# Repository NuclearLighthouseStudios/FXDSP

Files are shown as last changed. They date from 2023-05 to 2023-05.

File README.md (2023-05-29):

# FXDSP — A WhateverDSP based guitar pedal

FXDSP is an easily programmable DSP platform in a familiar guitar pedal form factor:

FXDSP collage

It's based around an STM32F405 microcontroller and runs on the [WhateverDSP framework](https://github.com/NuclearLighthouseStudios/WhateverDSP),
offering low latency audio processing and fully class complicant USB audio and MIDI support.

FXDSP has interchangeable user interface PCBs so it can easily be tailored to the needs of each effect produced on the platform.

For more information about WhateverDSP, [please see the WhateverDSP repository](https://github.com/NuclearLighthouseStudios/WhateverDSP).

## Example code

Here is a full example showing a simple volume control that scales the audio level using a potentiometer:

```c
#include <libwdsp.h>

void wdsp_init(void)
{
	io_digital_out(BYPASS_L, true);
	io_digital_out(BYPASS_R, true);
}

void wdsp_process(float *in_buffer[BLOCK_SIZE], float *out_buffer[BLOCK_SIZE])
{
	float volume = io_analog_in(POT_1);

	for (int i = 0; i < BLOCK_SIZE; i++)
	{
		float l_sample = in_buffer[0][i];
		float r_sample = in_buffer[1][i];

		out_buffer[0][i] = l_sample * volume;
		out_buffer[1][i] = r_sample * volume;
	}
}

```

Check out the [examples repository](https://github.com/NuclearLighthouseStudios/WhateverDSP-Examples) for more,
or [come chat with us on Discord](https://github.com/NuclearLighthouseStudios/FXDSP#chat).

## Chat

[You can chat with us on Discord.](https://discord.gg/WDsFnartXb)

## License

FXDSP hardware is licensed under CC-BY-NC-SA.

The WhateverDSP library is licensed under GNU Lesser General Public License.

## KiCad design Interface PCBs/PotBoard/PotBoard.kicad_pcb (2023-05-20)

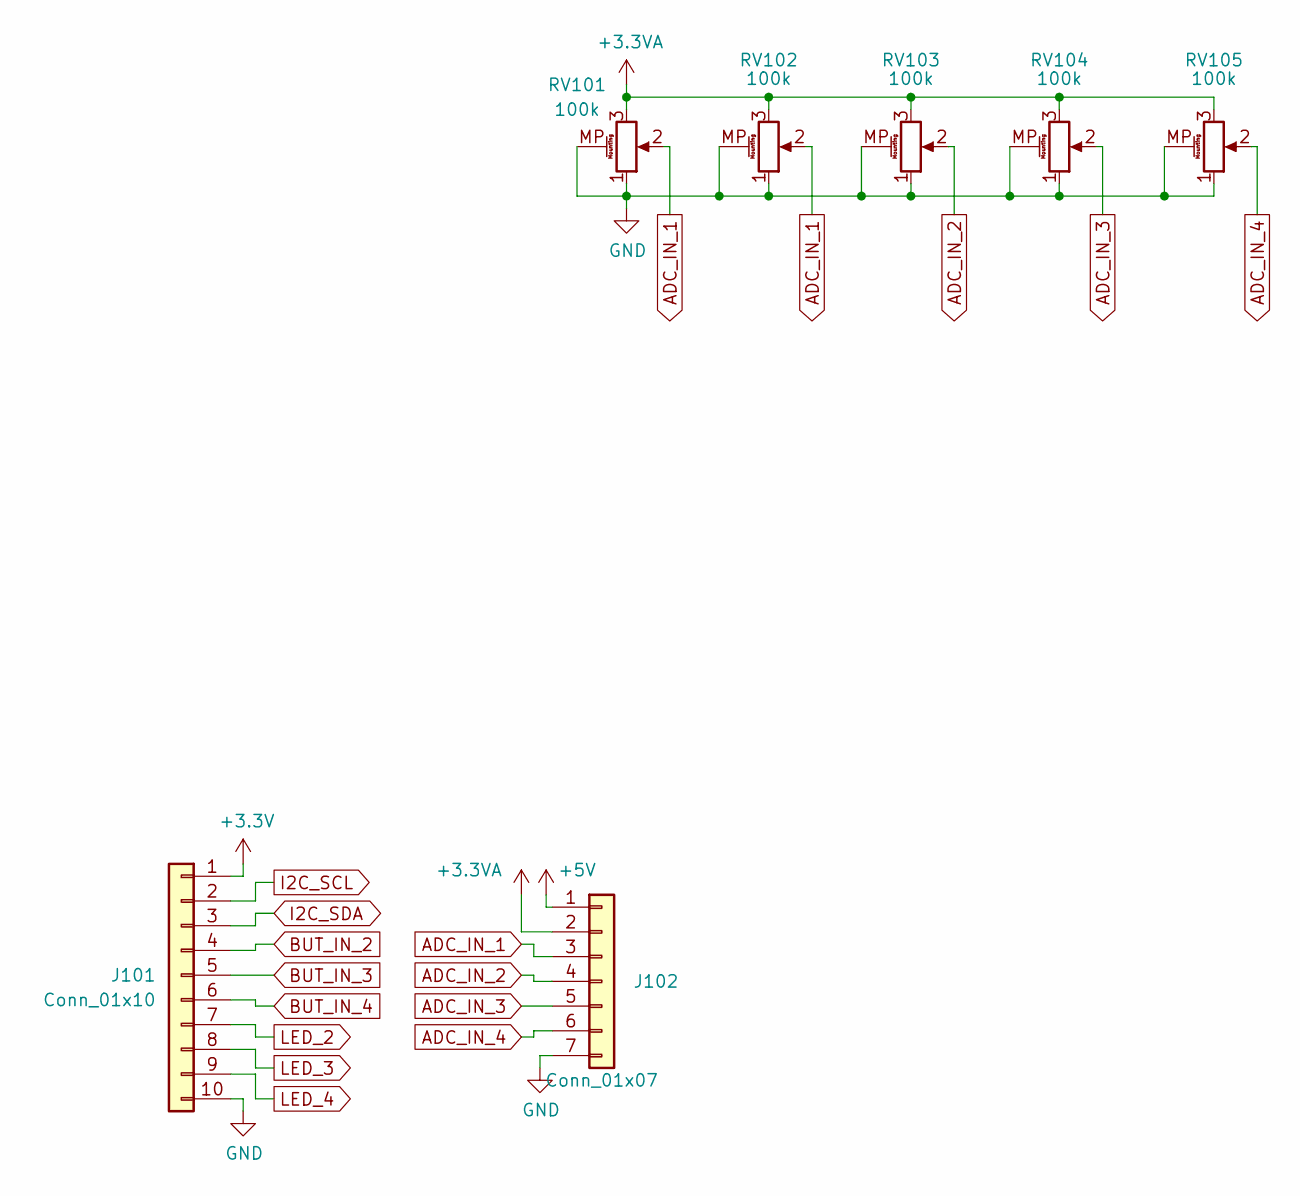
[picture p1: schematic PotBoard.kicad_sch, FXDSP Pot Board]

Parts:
J101: Conn_01x10; PinHeader_1x10_P2.54mm_Vertical
J102: Conn_01x07; PinHeader_1x07_P2.54mm_Vertical
RV101, RV102, RV103, RV104, RV105: 100k; Potentiometer_Alps_RK09K_Single_Vertical

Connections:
+3.3V: J101.1
+3.3VA: J102.2, RV101.3, RV102.3, RV103.3, RV104.3, RV105.3
+5V: J102.1
ADC_IN_1: J102.3, RV101.2, RV102.2
ADC_IN_2: J102.4, RV103.2
ADC_IN_3: J102.5, RV104.2
ADC_IN_4: J102.6, RV105.2
BUT_IN_2: J101.4
BUT_IN_3: J101.5
BUT_IN_4: J101.6
GND: J101.10, J102.7, RV101.1, RV101.MP (MountPin), RV102.1, RV102.MP (MountPin), RV103.1, RV103.MP (MountPin), RV104.1, RV104.MP (MountPin), RV105.1, RV105.MP (MountPin)
I2C_SCL: J101.2
I2C_SDA: J101.3
LED_2: J101.7
LED_3: J101.8
LED_4: J101.9

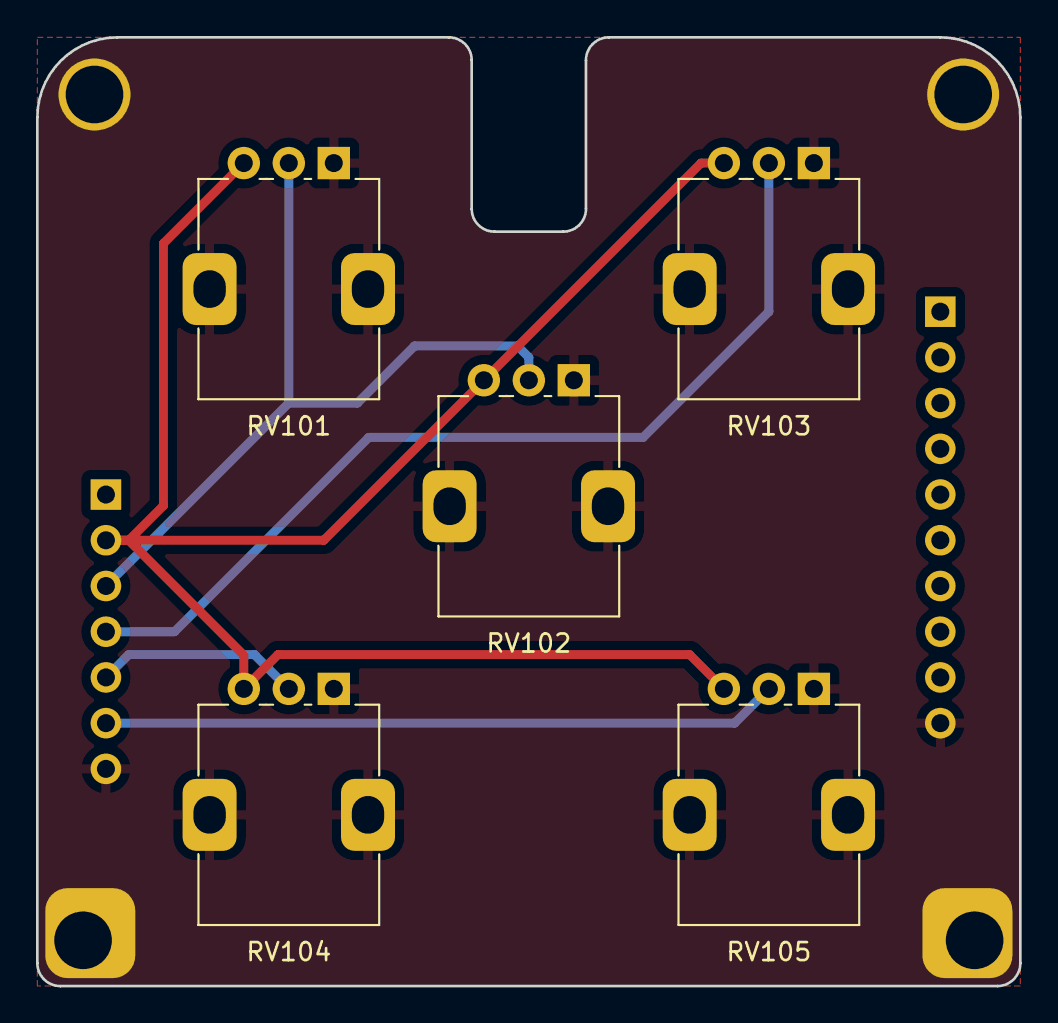
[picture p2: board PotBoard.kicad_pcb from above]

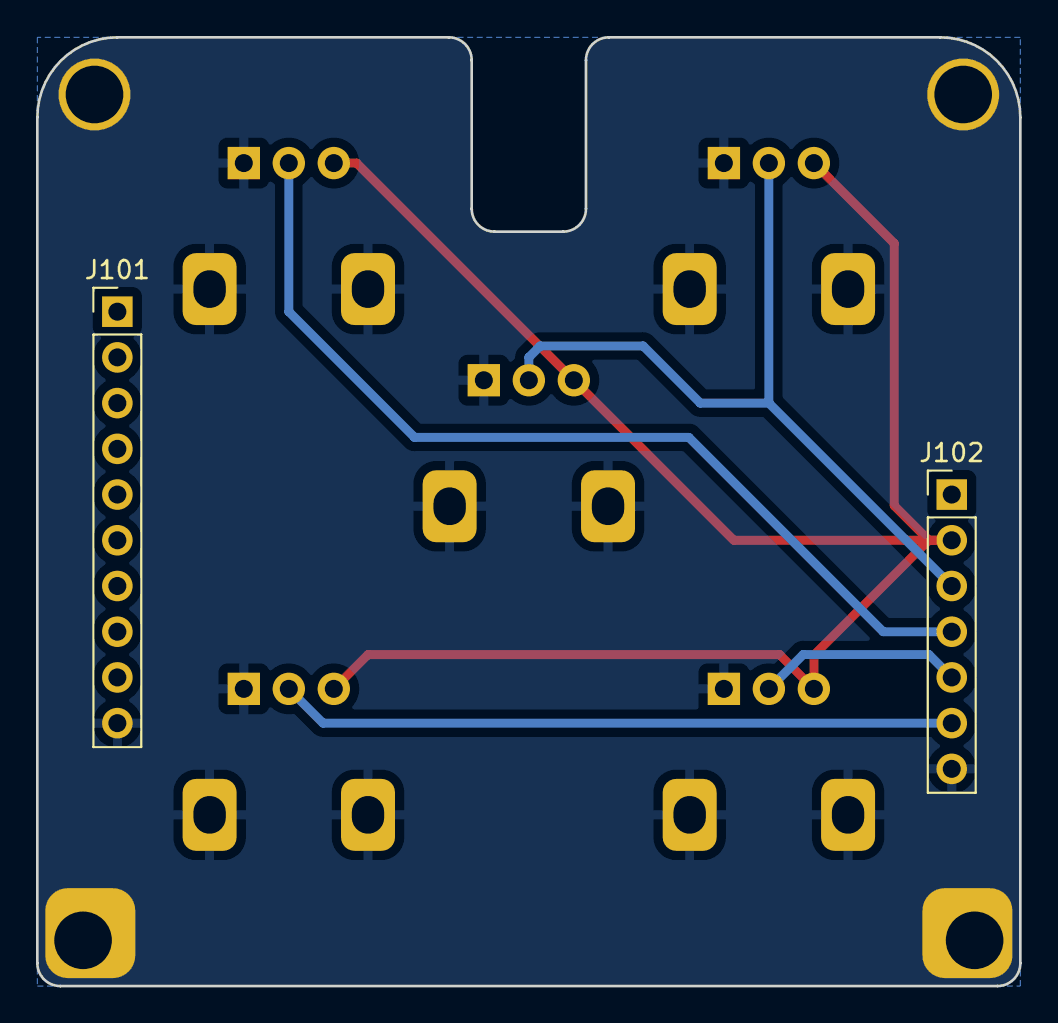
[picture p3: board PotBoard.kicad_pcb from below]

Board: 2 copper layers, 54.6 x 52.7 mm, 7 parts (2 on the bottom side), 6 nets.

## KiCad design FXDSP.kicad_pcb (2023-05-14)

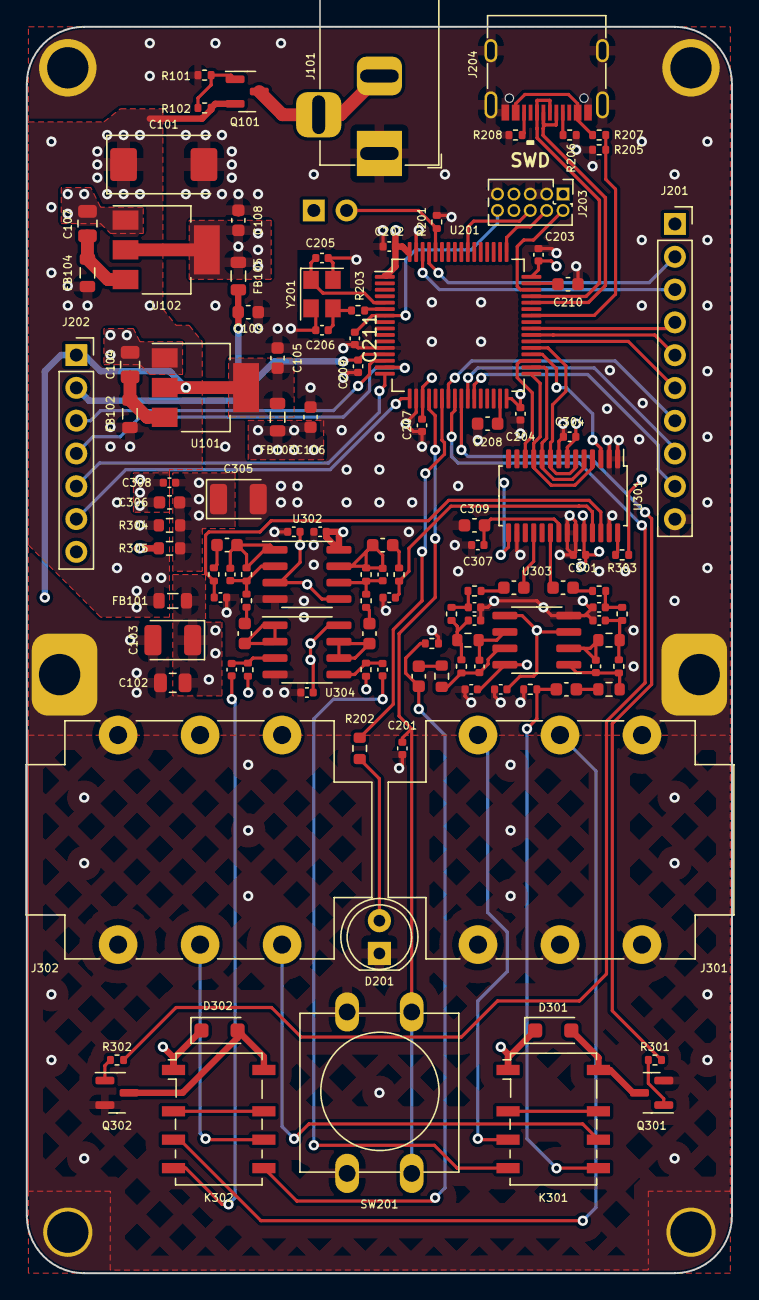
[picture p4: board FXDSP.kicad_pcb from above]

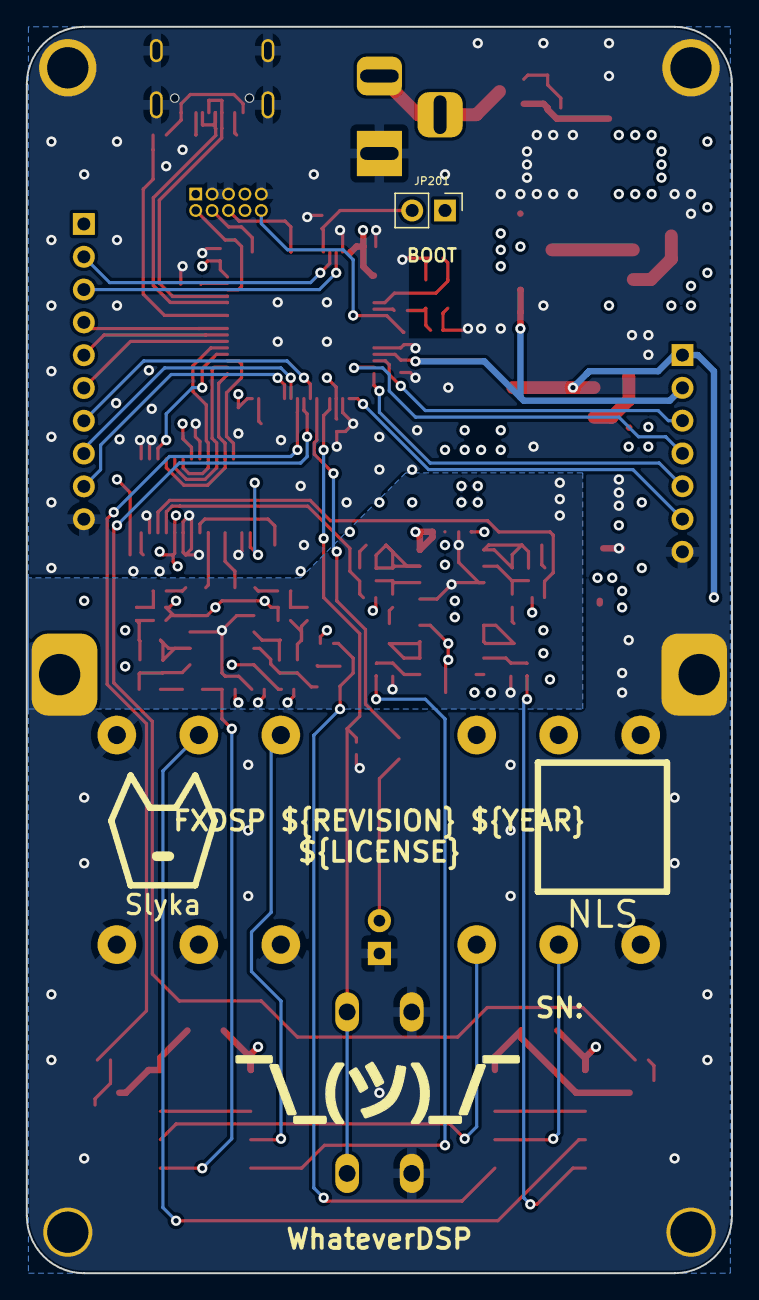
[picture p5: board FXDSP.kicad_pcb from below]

Board: 4 copper layers, 54.6 x 96.5 mm, 124 parts (3 on the bottom side), 94 nets.

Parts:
C101: 100µ; CP_EIA-7343-30_AVX-N
C102, C104, C107: 10µ; C_0805_2012Metric
C103: 47µ; CP_EIA-3528-21_Kemet-B
C105, C106, C108, C109, C306, C309, C312, C313, C316, C317, C327, C328, C329, C330: 10µ; C_0603_1608Metric
C201, C202, C203, C204, C207, C209, C211, C301, C302, C303, C304, C307, C308, C322, C325, C326, C331, C332: 100n; C_0402_1005Metric
C205, C206: 12pF; C_0402_1005Metric
C208, C210: 2.2µ; C_0603_1608Metric
C305: 100µ; CP_EIA-3528-21_Kemet-B
C310, C311: 1n; C_0402_1005Metric
C314, C315: 3.3n; C_0402_1005Metric
C318, C319: 150p; C_0402_1005Metric
C320, C321: 330p; C_0402_1005Metric
C323, C324: 10p; C_0402_1005Metric
D201: LED; LED_D5.0mm
D301, D302: SM4007; D_SOD-123F
FB101, FB103, FB105: 600; L_0805_2012Metric
FB102, FB104: 100; L_0805_2012Metric
H101, H102, H103, H104, H105, H106: MountingHole_Pad; MountingHole_3.2mm_M3_Pad
J101: Barrel_Jack_Switch; BarrelJack_Horizontal
J201: Conn_01x10; PinSocket_1x10_P2.54mm_Vertical
J202: Conn_01x07; PinSocket_1x07_P2.54mm_Vertical
J203: Conn_ARM_JTAG_SWD_10; PinHeader_2x05_P1.27mm_Vertical
J204: USB_C_Receptacle_USB2.0; USB_C_Receptacle_G-Switch_GT-USB-7010ASV
J301, J302: AudioJack3_Switch; Jack_6.35mm_Neutrik_NMJ6HCD2_Horizontal
JP201: Boot Jumper; PinHeader_1x02_P2.54mm_Vertical
K301, K302: G6K-2; Relay_DPDT_Omron_G6K-2F-Y
Q101: Si2301CDS; SOT-23
Q301, Q302: MMBT3904; SOT-23
R101: 22k; R_0402_1005Metric
R102, R201, R318, R319: 10k; R_0402_1005Metric
R202: 1k; R_0603_1608Metric
R203: 47; R_0402_1005Metric
R205: 2.2k; R_0402_1005Metric
R206, R208: 5.1k; R_0402_1005Metric
R207, R301, R302, R306, R307: 1k; R_0402_1005Metric
R303: 220k; R_0402_1005Metric
R304, R305: 10k; R_0603_1608Metric
R308, R309: 910; R_0402_1005Metric
R310, R311: 47k; R_0402_1005Metric
R312, R313: 8.6k; R_0402_1005Metric
R314, R316: 43k; R_0402_1005Metric
R315, R317: 130k; R_0603_1608Metric
R320, R321: 100; R_0603_1608Metric
R322, R323, R324, R325: 1M; R_0402_1005Metric
SW201: SW_Push; SW_PUSH-12mm
U101: NCP1117-5.0; SOT-223-3_TabPin2
U102: NCP1117-3.3; SOT-223-3_TabPin2
U201: STM32F405RGTx; LQFP-64_10x10mm_P0.5mm
U301: PCM3060; TSSOP-28_4.4x9.7mm_P0.65mm
U302, U303, U304: NE5532; SOIC-8_3.9x4.9mm_P1.27mm
Y201: 12.288Mhz; Crystal_SMD_3225-4Pin_3.2x2.5mm
foxlogo: foxlogo_nocopper
nlslogo: nlslogo_nocopper

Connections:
+3.3V: C108.1, C202.2, C203.2, C204.2, C207.2, C304.2, FB105.2, J201.1, J203.1 (VTref), JP201.1 (A), R303.1, U102.2 (VO), U201.1 (VBAT), U201.19 (VDD), U201.32 (VDD), U201.48 (VDD), U201.64 (VDD), U301.7 (V_{DD}), U301.15 (~RST)
+3.3VA: C109.1, C209.2, FB105.1, J202.2, U201.13 (VDDA)
+5V: C105.1, D301.1 (K), D302.1 (K), FB103.2, J202.1, K301.1, K302.1, U101.2 (VO)
+5VA: C106.1, C301.2, FB103.1, U301.24 (V_{CC})
+9V: C101.1, FB101.2, FB102.2, FB104.2, Q101.2 (S), R102.2, R304.1
+9VA: C102.1, C103.1, C322.1, C325.1, C326.1, FB101.1, U302.8 (V+), U303.8 (V+), U304.8 (V+)
/Audio/BCK: U201.34 (I2S2_CK), U301.5 (BCK1), U301.10 (BCK2)
/Audio/BYPASSL: R301.1, U201.25 (PC5)
/Audio/BYPASSR: R302.1, U201.24 (PC4)
/Audio/DIN: U201.35 (I2S2_ext_SD), U301.12 (DIN)
/Audio/DOUT: U201.36 (I2S2_SD), U301.3 (DOUT)
/Audio/LRCK: U201.33 (I2S2_WS), U301.4 (LRCK1), U301.11 (LRCK2)
/Audio/SCK: U201.37 (I2S2_MCK), U301.6 (SCKI1), U301.9 (SCKI2)
/V_IN: J101.2, J101.3, Q101.3 (D)
ADC_IN_1: J202.3, U201.14 (ADC1_IN0)
ADC_IN_2: J202.4, U201.15 (ADC1_IN1)
ADC_IN_3: J202.5, U201.16 (ADC1_IN2)
ADC_IN_4: J202.6, U201.17 (ADC1_IN3)
BOOT0: JP201.2 (B), R201.1, U201.60 (BOOT0)
BUT_IN_1: C201.1, SW201.2, U201.20 (PA4)
BUT_IN_2: J201.4, U201.40 (PC9)
BUT_IN_3: J201.5, U201.39 (PC8)
BUT_IN_4: J201.6, U201.38 (PC7)
CODEC_COM: C307.1, C309.1, U301.21 (V_{COM})
COIL_L: D301.2 (A), K301.8, Q301.3 (C)
COIL_R: D302.2 (A), K302.8, Q302.3 (C)
GND: C101.2, C102.2, C103.2, C104.2, C105.2, C106.2, C107.2, C108.2, C109.2, C201.2, C202.1, C203.1, C204.1, C205.2, C206.2, C207.1, C208.2, C209.1, C210.2, C211.2, C301.1, C302.2, C303.2, C304.1, C305.2, C306.2, C307.2, C308.2, C309.2, C310.2, C311.1, C314.2, C315.2, C318.2, C319.2, C322.2, C325.2, C326.2, D201.1 (K), H101.1, H102.1, H103.1, H104.1, H105.1, H106.1, J101.1, J201.10, J202.7, J203.3 (GND), J203.5 (GND), J203.9 (GNDDetect), J204.A1 (GND), J204.A12 (GND), J204.B1 (GND), J204.B12 (GND), J204.S1 (SHIELD), J301.RN, J301.S, J301.SN, J301.TN, J302.S, J302.SN, Q301.2 (E), Q302.2 (E), R101.2, R201.2, R205.2, R206.2, R208.2, R305.2, R324.2, R325.2, SW201.1, U101.1 (GND), U102.1 (GND), U201.12 (VSSA), U201.18 (VSS), U201.63 (VSS), U301.1 (MC/SCL/FMT), U301.2 (MD/SDA/DEMP), U301.8 (DGND), U301.16 (SGND), U301.22 (AGND2), U301.23 (AGND1), U301.27 (~MS/ADR/IFMD), U302.4 (V-), U303.4 (V-), U304.4 (V-), Y201.2, Y201.4
GNDA: C302.1, C303.1, C305.1, C306.1, C308.1, R304.2, R305.1, R322.1, R323.1, U302.3 (+), U302.5 (+), U303.3 (+), U303.5 (+)
I2C_SCL: J201.2, U201.61 (I2C1_SCL)
I2C_SDA: J201.3, U201.62 (I2C1_SDA)
LED_1: R202.2, U201.22 (TIM3_CH1)
LED_2: J201.7, U201.23 (TIM3_CH2)
LED_3: J201.8, U201.26 (TIM3_CH3)
LED_4: J201.9, U201.27 (TIM3_CH4)
NRST: C211.1, J203.10 (~RESET), U201.7 (NRST)
unnamed: C104.1, FB102.1, U101.3 (VI)
unnamed: C107.1, FB104.1, U102.3 (VI)
unnamed: C206.1, R203.2, Y201.3
unnamed: C312.2, R308.2
unnamed: C313.2, R309.2
unnamed: C314.1, R308.1, R310.2
unnamed: C315.1, R309.1, R311.2
unnamed: C316.1, C320.2, R312.2, U302.7
unnamed: C316.2, R306.1
unnamed: C317.1, C321.2, R313.2, U302.1
unnamed: C317.2, R307.1
unnamed: C318.1, R310.1, R314.2, R315.2
unnamed: C319.1, R311.1, R316.2, R317.2
unnamed: C323.1, R314.1, R320.2, U303.1
unnamed: C324.1, R316.1, R321.2, U303.7
unnamed: C327.2, R318.1
unnamed: C328.2, R319.1
unnamed: C329.1, R320.1
unnamed: C329.2, K301.5, R324.1
unnamed: C330.1, R321.1
unnamed: C330.2, K302.5, R325.1
unnamed: C331.2, K301.4
unnamed: C332.2, K302.4
unnamed: D201.2 (A), R202.1
unnamed: J204.A5 (CC1), R206.1
unnamed: J204.B5 (CC2), R208.1
unnamed: J204.A4 (VBUS), J204.A9 (VBUS), J204.B4 (VBUS), J204.B9 (VBUS), R207.1
unnamed: J301.R, K302.3
unnamed: J301.T, K301.3
unnamed: J302.R, K302.6
unnamed: J302.T, K301.6
unnamed: K301.2, K301.7
unnamed: K302.2, K302.7
unnamed: Q101.1 (G), R101.1, R102.1
unnamed: Q301.1 (B), R301.2
unnamed: Q302.1 (B), R302.2
unnamed: C205.1, U201.5 (RCC_OSC_IN), Y201.1
unnamed: R203.1, U201.6 (RCC_OSC_OUT)
unnamed: C208.1, U201.31 (VCAP_1)
unnamed: C210.1, U201.47 (VCAP_2)
unnamed: R303.2, U301.28 (MODE)
unnamed: C310.1, R306.2, U301.25 (V_{IN}L)
unnamed: C311.2, R307.2, U301.26 (V_{IN}R)
unnamed: C312.1, U301.20 (V_{OUT}L+)
unnamed: C313.1, U301.18 (V_{OUT}R+)
unnamed: C321.1, R313.1, R319.2, U302.2 (-)
unnamed: C320.1, R312.1, R318.2, U302.6 (-)
unnamed: C323.2, R315.1, U303.2 (-)
unnamed: C324.2, R317.1, U303.6 (-)
unnamed: C332.1, R323.2, U304.3 (+)
unnamed: C328.1, U304.1, U304.2 (-)
unnamed: C331.1, R322.2, U304.5 (+)
unnamed: C327.1, U304.6 (-), U304.7
SWCLK: J203.4 (SWDCLK/TCK), U201.49 (SYS_JTCK-SWCLK)
SWDIO: J203.2 (SWDIO/TMS), U201.46 (SYS_JTMS-SWDIO)
SWO: J203.6 (SWO/TDO), U201.55 (SYS_JTDO-SWO)
USB_D+: J204.A6 (D+), J204.B6 (D+), U201.45 (USB_OTG_FS_DP)
USB_D-: J204.A7 (D-), J204.B7 (D-), U201.44 (USB_OTG_FS_DM)
USB_VBUS: R205.1, R207.2, U201.42 (USB_OTG_FS_VBUS)

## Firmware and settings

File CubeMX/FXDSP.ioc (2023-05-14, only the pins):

Mcu.UserName=STM32F405RGTx
PA0-WKUP.Signal=ADCx_IN0
PA1.Signal=ADCx_IN1
PA11.Signal=USB_OTG_FS_DM
PA12.Signal=USB_OTG_FS_DP
PA13.Signal=SYS_JTMS-SWDIO
PA14.Signal=SYS_JTCK-SWCLK
PA2.Signal=ADCx_IN2
PA3.Signal=ADCx_IN3
PA4.GPIO_Label=BUTTON_1
PA4.Signal=GPIO_Input
PA6.GPIO_Label=LED_1
PA6.Signal=S_TIM3_CH1
PA7.GPIO_Label=LED_2
PA7.Signal=S_TIM3_CH2
PA9.Signal=USB_OTG_FS_VBUS
PB0.GPIO_Label=LED_3
PB0.Signal=S_TIM3_CH3
PB1.GPIO_Label=LED_4
PB1.Signal=S_TIM3_CH4
PB12.Signal=I2S2_WS
PB13.Signal=I2S2_CK
PB14.Signal=I2S2_ext_SD
PB15.Signal=I2S2_SD
PB3.Signal=SYS_JTDO-SWO
PB8.Signal=I2C1_SCL
PB9.Signal=I2C1_SDA
PC4.GPIO_Label=BYPASS_R
PC4.Signal=GPIO_Output
PC5.GPIO_Label=BYPASS_L
PC5.Signal=GPIO_Output
PC6.Signal=I2S2_MCK
PC7.GPIO_Label=BUTTON_4
PC7.Signal=GPIO_Input
PC8.GPIO_Label=BUTTON_3
PC8.Signal=GPIO_Input
PC9.GPIO_Label=BUTTON_2
PC9.Signal=GPIO_Input
PH0-OSC_IN.Signal=RCC_OSC_IN
PH1-OSC_OUT.Signal=RCC_OSC_OUT

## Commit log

2023-04-02 Initial Commit of FXDSP board
    Added WDSP logo and serial number field missing from version ordered
    from JLCPCB
    [FXDSP.kicad_pcb, FXDSP.kicad_sch, audio.kicad_sch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]
2023-05-14 Fix reset problems from r01 PCB
    [FXDSP.kicad_pcb, audio.kicad_sch, digital.kicad_sch]
2023-05-14 Add PotBoard interface PCB
    [PotBoard.kicad_pcb, PotBoard.kicad_sch]
2023-05-20 Correct positioning of lower potentiometers on interface PCB
    [PotBoard.kicad_pcb]

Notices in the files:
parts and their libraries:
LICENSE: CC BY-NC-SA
